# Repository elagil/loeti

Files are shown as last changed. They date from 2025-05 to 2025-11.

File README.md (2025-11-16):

# Löti

Soldering station hardware and firmware, powered by USB PD, delivering up to 100 W.

Supports irons with thermocouples as temperature probes, for example
- JBC C210
- JBC C245

## Resources

- [Hardware design](./hardware)
- [Firmware](./firmware)

## Updating firmware

On the device, either
- hold the `BOOT`-button on the PCB and insert the USB cable into the data/debug port, or
- go to the user menu (long-press encoder button), scroll down to `DFU mode`, and select.

Once in DFU mode, flash a binary from the release artifacts. For example with

```bash
dfu-util -a 0 -s 0x08000000:leave -D <firmware_file_name>.bin
```

## The finished product

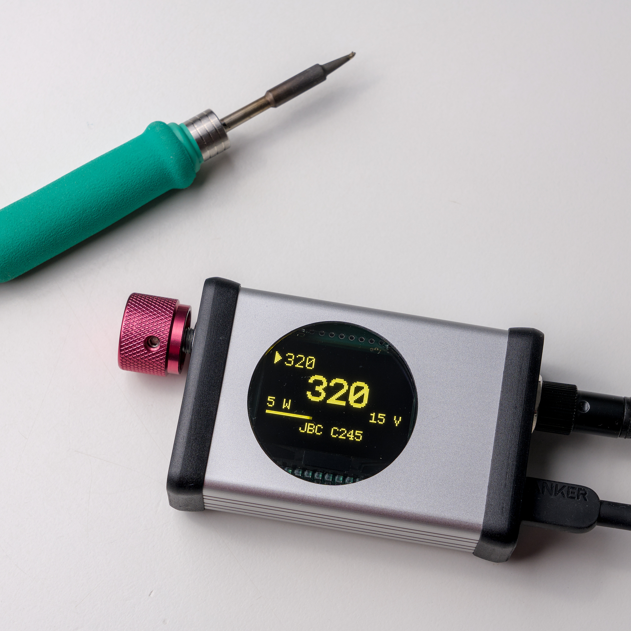
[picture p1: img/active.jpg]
Active

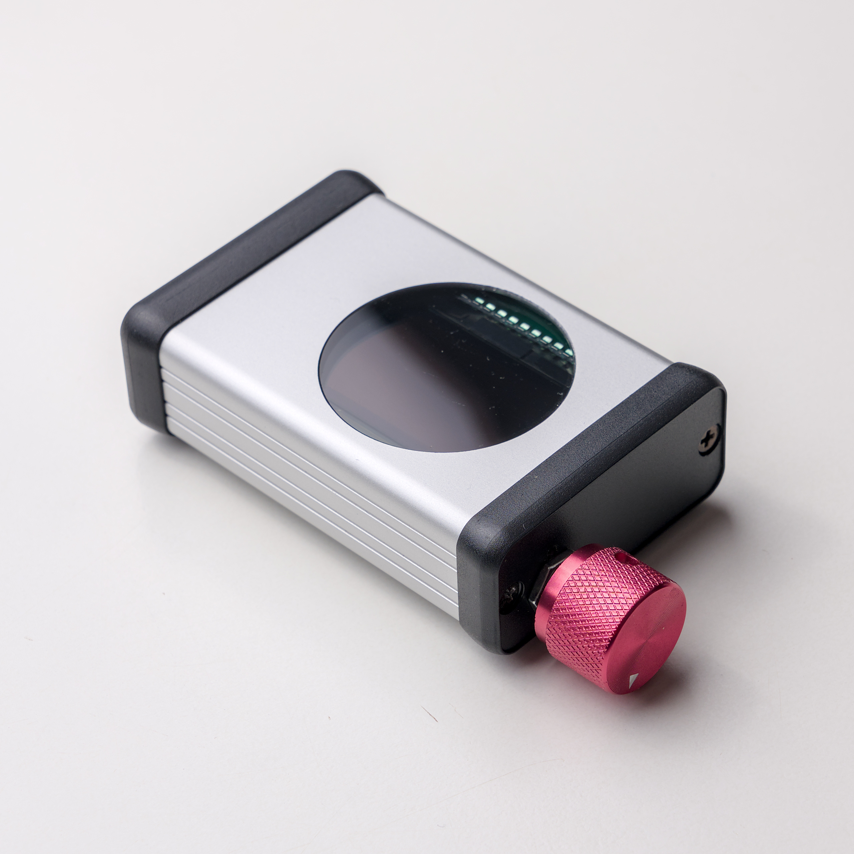
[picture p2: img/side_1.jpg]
Side 1

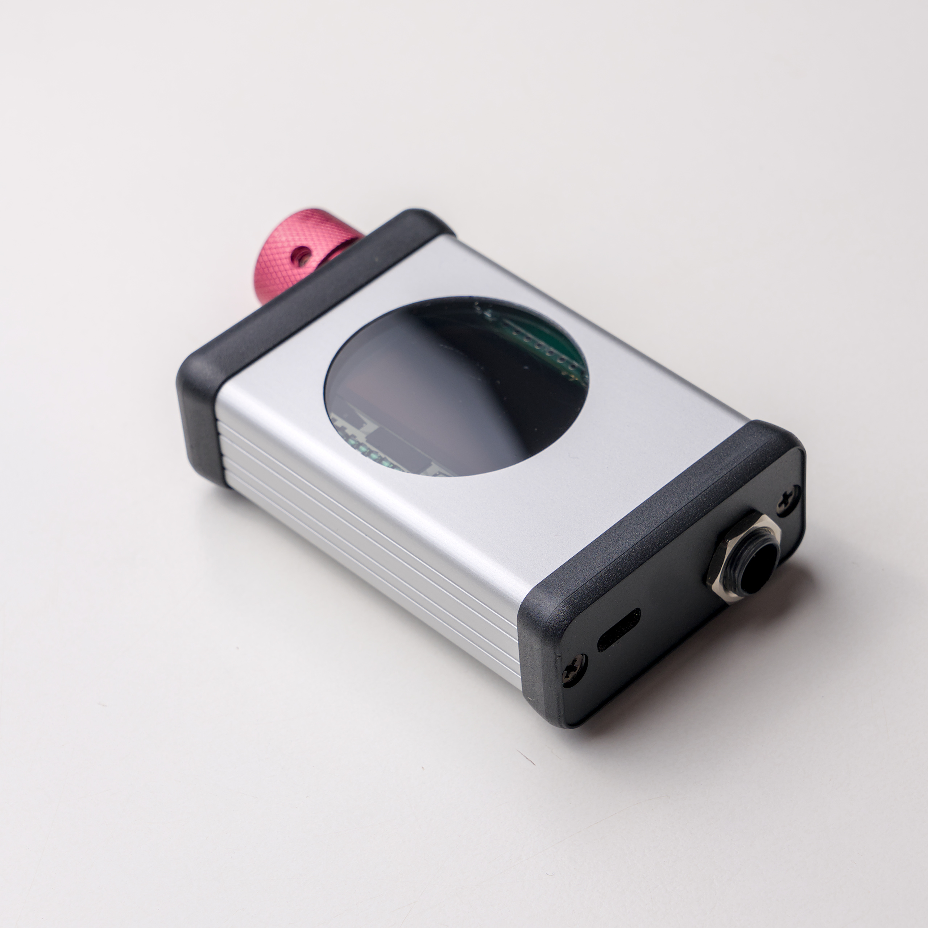
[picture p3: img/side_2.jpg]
Side 2

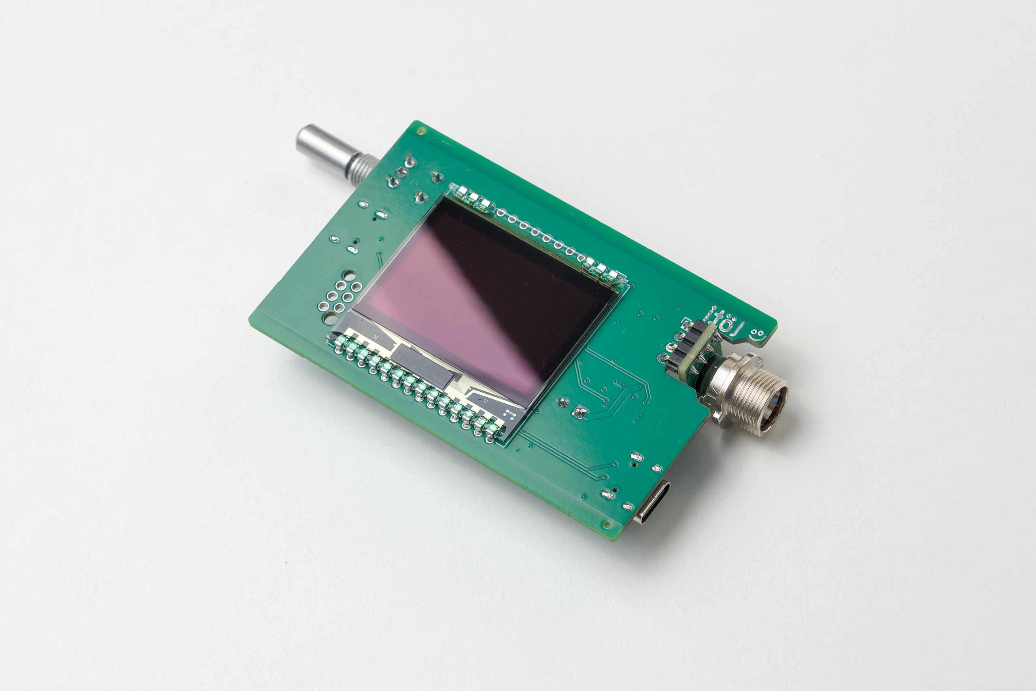
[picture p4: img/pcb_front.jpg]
Front

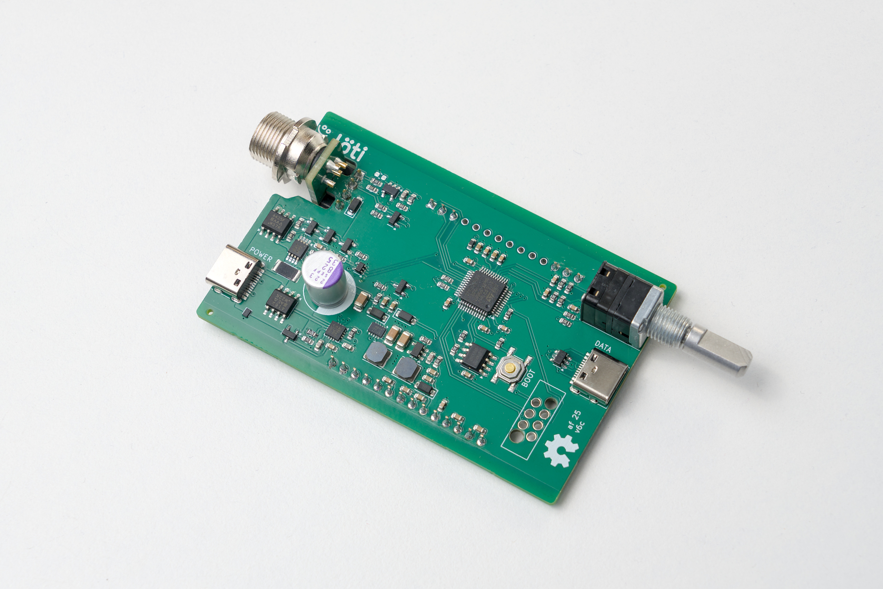
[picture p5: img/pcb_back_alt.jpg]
Back alt

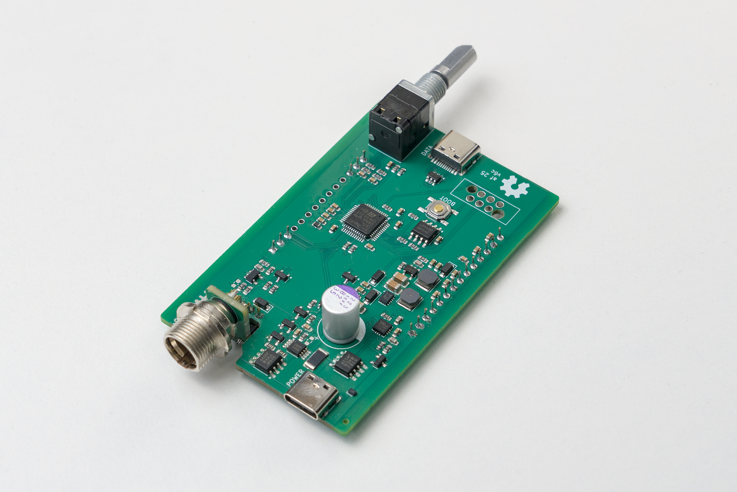
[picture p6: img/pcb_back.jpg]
Back


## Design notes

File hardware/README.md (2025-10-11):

# Hardware design

There are three PCBs that complete the build.

- The [main PCB](pcbs/main/),
- the [REAN TinyXLR adapter board](pcbs/adapter/), and
- a [holder for the acrylic display protection glass](pcbs/holder/).

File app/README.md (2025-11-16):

# Graphical user application

This is a GUI for observing the PID filter operation. It can be used to manually tune the PID filter in firmware.

## Usage

- Start this application with `RUST_LOG=INFO cargo run`.
- Connect a device that was built with the `comm` feature enabled.
- Display should start automatically.

## Permissions

On Linux, udev rules may have to be adjusted. Place [the rules file](./99-ergot.rules) in `/etc/udev/rules.d/` and run

```bash
sudo udevadm control --reload-rules && sudo udevadm trigger
```

for reloading the rules.

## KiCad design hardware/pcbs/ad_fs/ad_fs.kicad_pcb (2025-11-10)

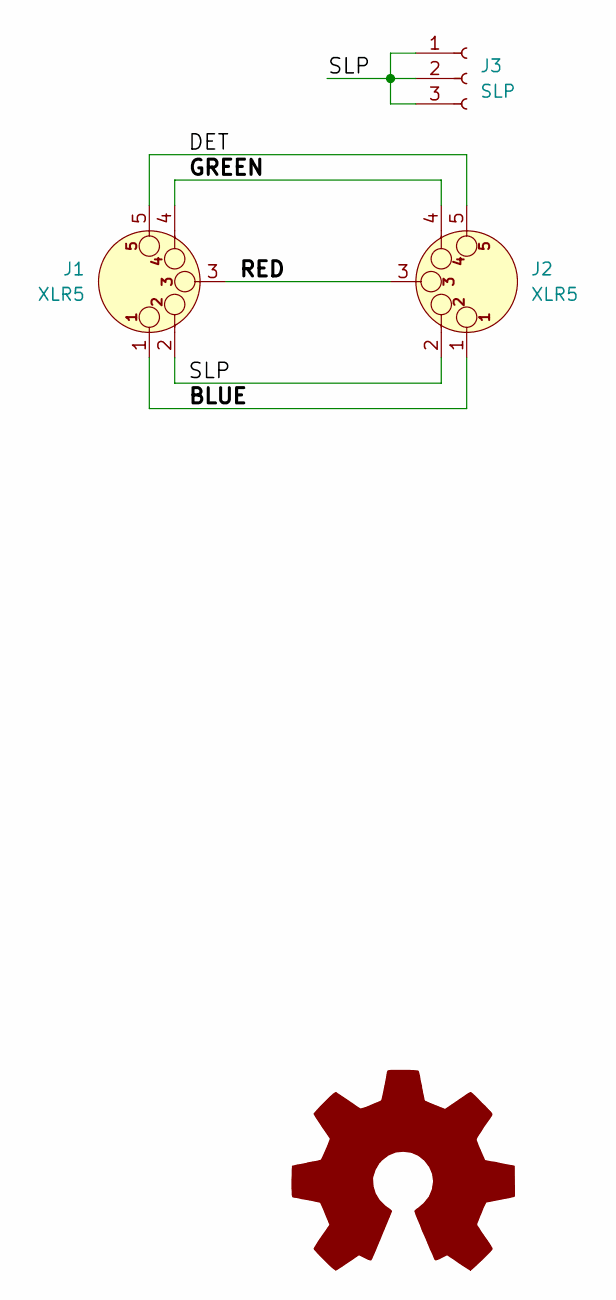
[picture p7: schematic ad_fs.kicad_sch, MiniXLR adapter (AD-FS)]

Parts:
J1, J2: XLR5; MiniXLR-5_Rean_RT5MPR
J3: SLP; PinSocket_1x03_P2.00mm_Vertical
oshw1: Logo_Open_Hardware_Large; OSHW-Symbol_6.7x6mm_SilkScreen

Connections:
/BLUE: J1.1, J2.1
/DET: J1.5, J2.5
/GREEN: J1.4 (P3), J2.4 (P3)
/RED: J1.3, J2.3
/SLP: J1.2, J2.2, J3.1, J3.2, J3.3

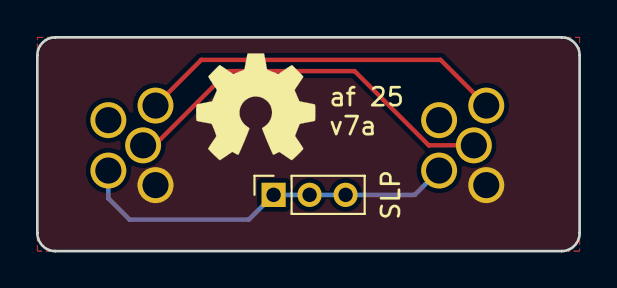
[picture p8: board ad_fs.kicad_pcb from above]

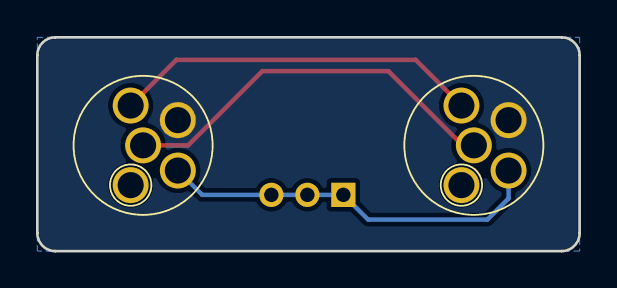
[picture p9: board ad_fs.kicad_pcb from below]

Board: 2 copper layers, 30.1 x 11.9 mm, 4 parts (2 on the bottom side), 5 nets.

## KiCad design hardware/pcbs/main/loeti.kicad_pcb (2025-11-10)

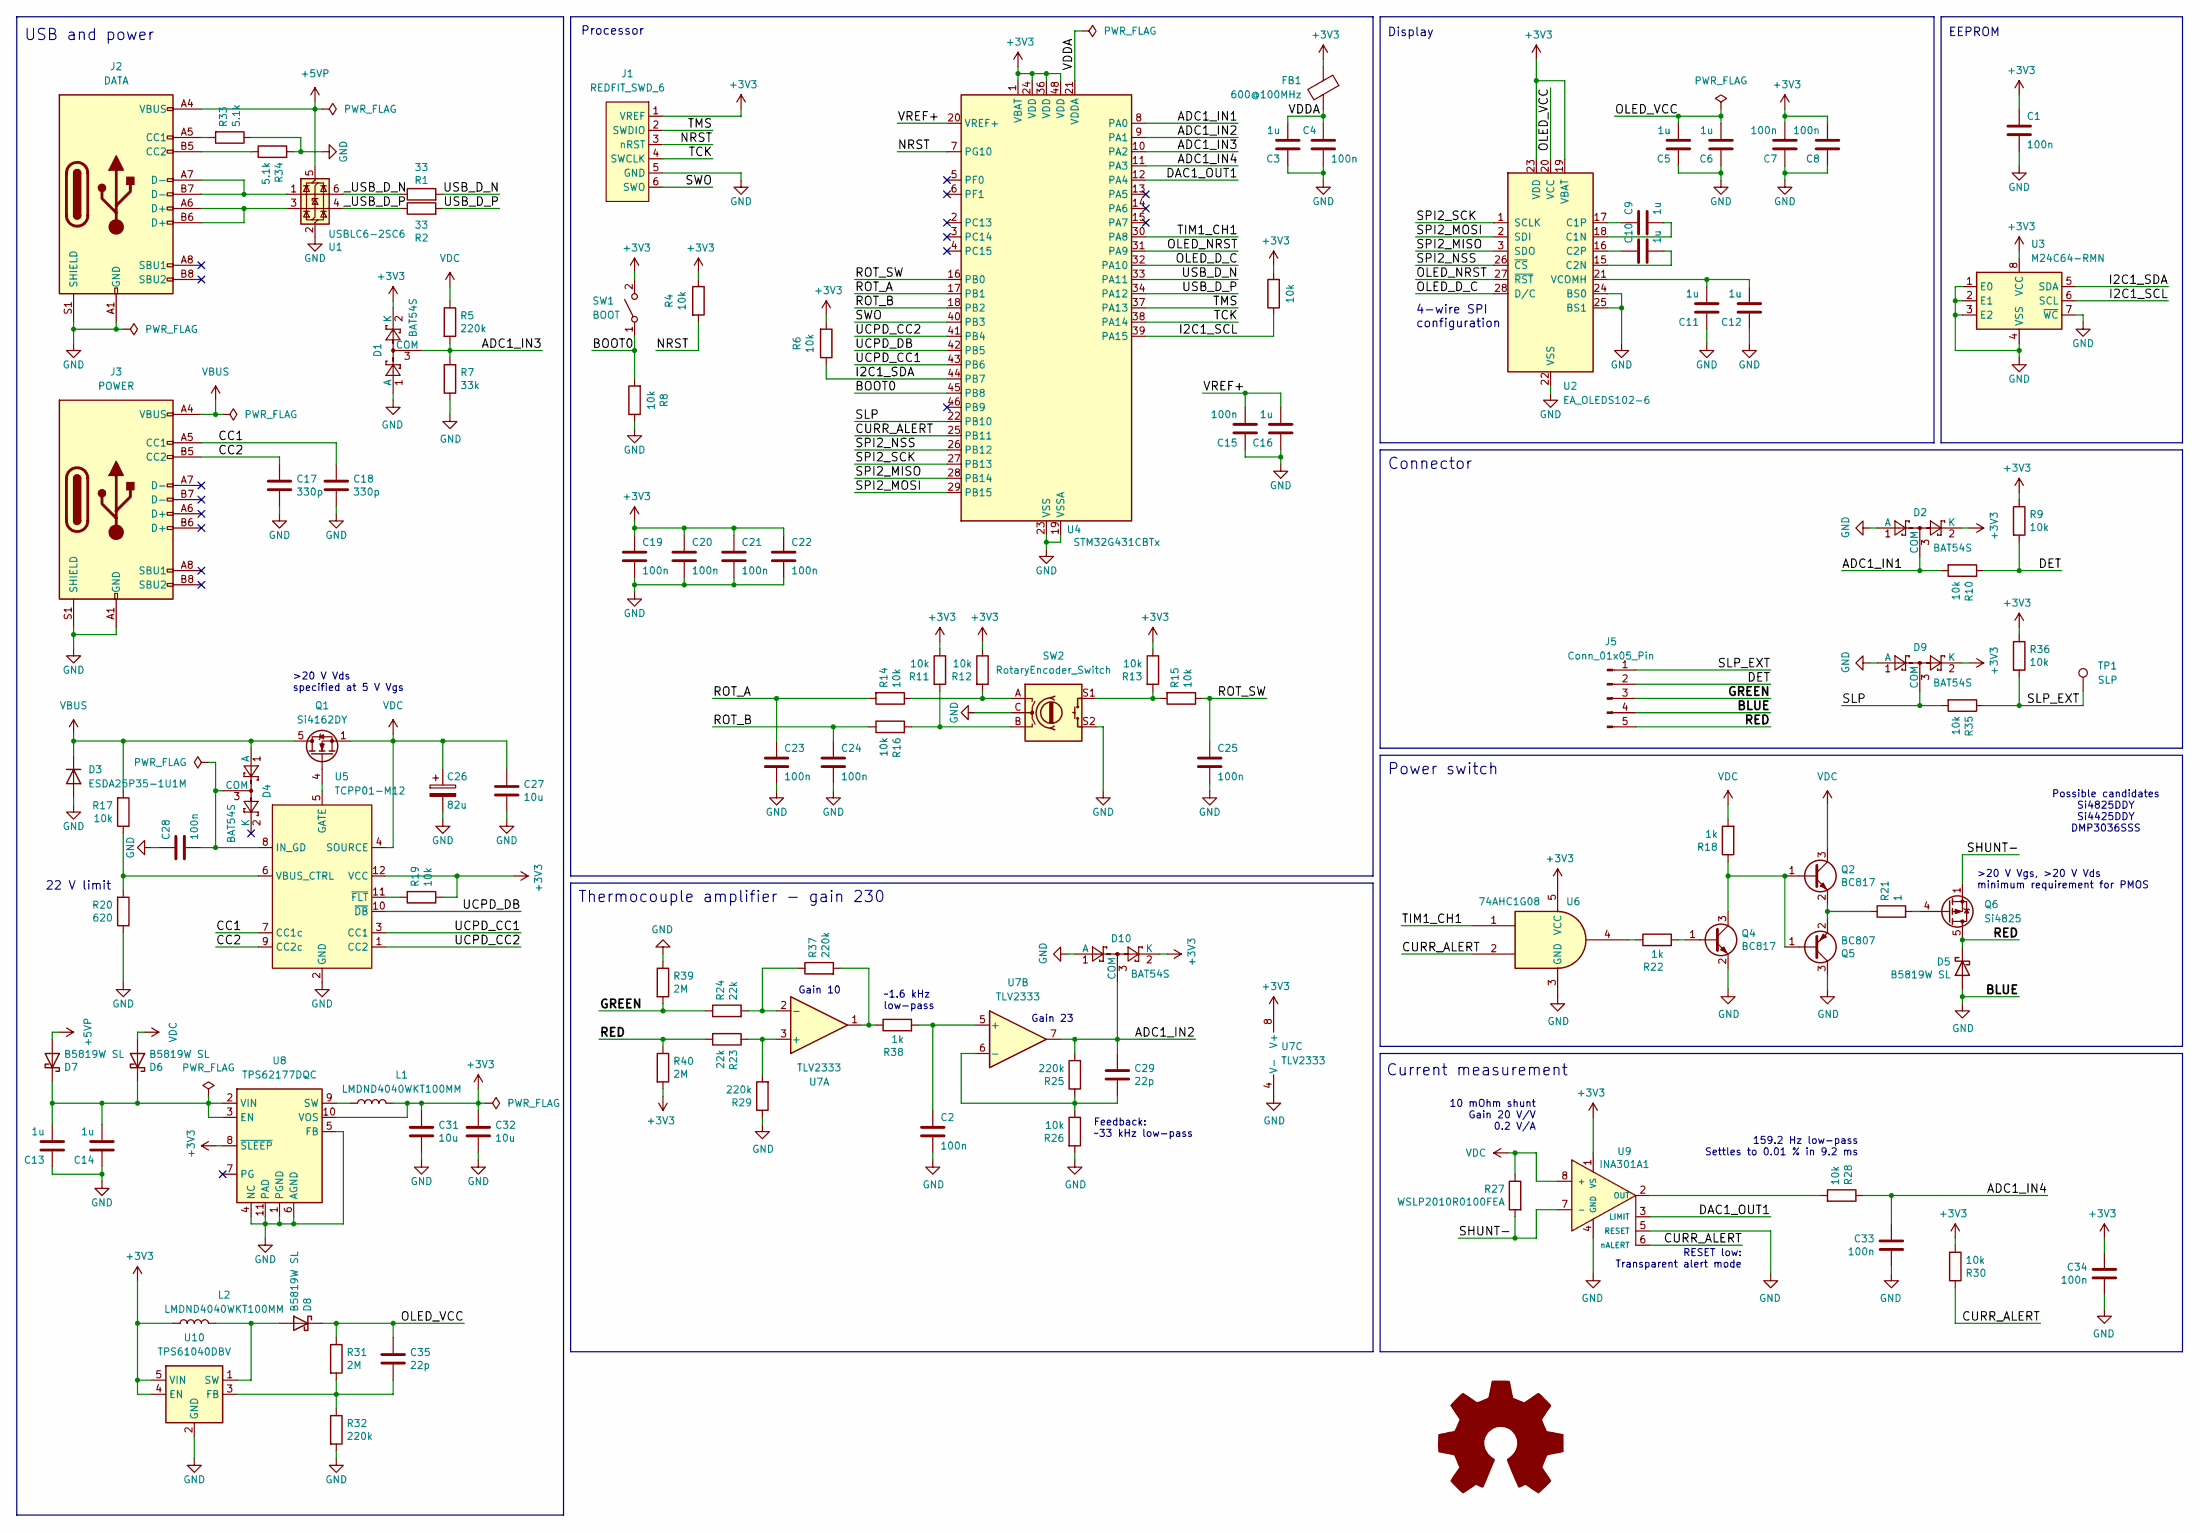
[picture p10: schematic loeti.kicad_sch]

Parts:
C1, C2, C4, C7, C8, C15, C19, C20, C21, C22, C23, C24, C25, C28, C33, C34: 100n; C_0603_1608Metric; MPN C14663
C3, C5, C6, C9, C10, C11, C12, C13, C14, C16: 1u; C_0603_1608Metric; MPN C15849
C17, C18: 330p; C_0603_1608Metric; MPN C1664
C26: 82u; CP_Radial_D8.0mm_P3.50mm
C27, C31, C32: 10u; C_1206_3216Metric; MPN C13585
C29, C35: 22p; C_0603_1608Metric; MPN C1653
D1, D2, D4, D9, D10: BAT54S; SOT-23; MPN C83935
D3: ESDA25P35-1U1M; ST_QFN-2L_1.6x1.0mm; MPN C1974707
D5, D6, D7, D8: B5819W SL; D_SOD-123; MPN C8598
FB1: 600@100MHz; L_0603_1608Metric; MPN C1002
J1: REDFIT_SWD_6; WR-WST REDFIT IDC 6 DBG
J2: DATA; USB_C_Receptacle_HRO_TYPE-C-31-M-12; MPN C165948
J3: POWER; USB_C_Receptacle_HRO_TYPE-C-31-M-12; MPN C165948
J5: Conn_01x05_Pin; PinHeader_1x05_P2.54mm_Horizontal
L1, L2: LMDND4040WKT100MM; L_Abracon_ASPI-0425
Q1: Si4162DY; SOIC-8_3.9x4.9mm_P1.27mm; MPN C727585
Q2, Q4: BC817; SOT-23; MPN C466643
Q5: BC807; SOT-23; MPN C466642
Q6: Si4825; SOIC-8_3.9x4.9mm_P1.27mm; MPN C3289788
R1, R2: 33; R_0603_1608Metric; MPN C23140
R3, R4, R6, R8, R9, R10, R11, R12, R13, R14, R15, R16, R17, R19, R26, R28, R30, R35, R36: 10k; R_0603_1608Metric; MPN C25804
R5, R25, R29, R32, R37: 220k; R_0603_1608Metric; MPN C22961
R7: 33k; R_0603_1608Metric; MPN C4216
R18, R22, R38: 1k; R_0603_1608Metric; MPN C21190
R20: 620; R_0603_1608Metric
R21: 1; R_0603_1608Metric; MPN C22936
R23, R24: 22k; R_0603_1608Metric; MPN C31850
R27: WSLP2010R0100FEA; R_2010_5025Metric; MPN C844087
R31, R39, R40: 2M; R_0603_1608Metric; MPN C22976
R33, R34: 5.1k; R_0603_1608Metric; MPN C23186
SW1: BOOT; SW_SPST_TL3342; MPN C318884
SW2: RotaryEncoder_Switch; RotaryEncoder_Bourns_Horizontal_PEC09-2xxxF-Sxxxx
TP1: SLP; TestPoint_Plated_Hole_D2.0mm
U1: USBLC6-2SC6; SOT-23-6; MPN C7519; JLCPCB Rotation Offset 180
U2: EA_OLEDS102-6
U3: M24C64-RMN; SOIC-8_3.9x4.9mm_P1.27mm; MPN C79988; JLCPCB Rotation Offset -90
U4: STM32G431CBTx; LQFP-48_7x7mm_P0.5mm; MPN C529355
U5: TCPP01-M12; QFN-12-1EP_3x3mm_P0.51mm_EP1.45x1.45mm; MPN C1121848
U6: 74AHC1G08; SOT-353_SC-70-5; MPN C459531
U7: TLV2333; SOIC-8_3.9x4.9mm_P1.27mm; MPN C176649
U8: TPS62177DQC; WSON-10-1EP_2x3mm_P0.5mm_EP0.84x2.4mm_ThermalVias; MPN C91241
U9: INA301A1; VSSOP-8_3x3mm_P0.65mm; MPN C471062
U10: TPS61040DBV; SOT-23-5
oshw1: Logo_Open_Hardware_Large; OSHW-Symbol_6.7x6mm_SilkScreen

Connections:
+3V3: C1.1, C7.2, C8.2, C19.1, C20.1, C21.1, C22.1, C31.1, C32.1, C34.1, D1.2 (K), D2.2 (K), D9.2 (K), D10.2 (K), FB1.1, J1.1 (VREF), L1.2, L2.1, R3.2, R4.1, R6.2, R9.1, R11.1, R12.1, R13.1, R19.1, R30.2, R36.1, R40.2, SW1.2 (B), U2.19 (VBAT), U2.23 (VDD), U3.8 (VCC), U4.1 (VBAT), U4.24 (VDD), U4.36 (VDD), U4.48 (VDD), U5.12 (VCC), U6.5 (VCC), U7.8 (V+), U8.8 (~SLEEP), U8.10 (VOS), U9.1 (VS), U10.4 (EN), U10.5 (VIN)
+5VP: D7.2 (A), J2.A4 (VBUS), J2.A9 (VBUS), J2.B4 (VBUS), J2.B9 (VBUS), U1.5 (VBUS)
/ADC1_IN1: D2.3 (COM), R10.2, U4.8 (PA0)
/ADC1_IN2: C29.1, D10.3 (COM), R25.2, U4.9 (PA1), U7.7
/ADC1_IN3: D1.3 (COM), R5.2, R7.2, U4.10 (PA2)
/ADC1_IN4: C33.1, R28.1, U4.11 (PA3)
/BOOT0: R8.2, SW1.1 (A), U4.45 (PB8)
/CC1: C18.1, J3.A5 (CC1), U5.7 (CC1c)
/CC2: C17.1, J3.B5 (CC2), U5.9 (CC2c)
/CURR_ALERT: R30.1, U4.25 (PB11), U6.2, U9.6 (nALERT)
/DAC1_OUT1: U4.12 (PA4), U9.3 (LIMIT)
/DET: J5.2, R9.2, R10.1
/GREEN: J5.3, R24.1, R39.2
/I2C1_SCL: R3.1, U3.6 (SCL), U4.39 (PA15)
/I2C1_SDA: R6.1, U3.5 (SDA), U4.44 (PB7)
/NRST: J1.3 (nRST), R4.2, U4.7 (PG10)
/OLED_D_C: U2.28 (D/C), U4.32 (PA10)
/OLED_NRST: U2.27 (~RST), U4.31 (PA9)
/OLED_VCC: C5.2, C6.2, C35.1, D8.1 (K), R31.1, U2.20 (VCC)
/RED: D5.1 (K), J5.5, Q6.5 (D), Q6.6 (D), Q6.7 (D), Q6.8 (D), R23.2, R40.1
/ROT_A: C23.1, R14.2, U4.17 (PB1)
/ROT_B: C24.1, R16.1, U4.18 (PB2)
/ROT_SW: C25.1, R15.1, U4.16 (PB0)
/SHUNT-: Q6.1 (S), Q6.2 (S), Q6.3 (S), R27.2, U9.7 (-)
/SLP: D9.3 (COM), R35.2, U4.22 (PB10)
/SLP_EXT: J5.1, R35.1, R36.2, TP1.1
/SPI2_MISO: U2.3 (SDO), U4.28 (PB14)
/SPI2_MOSI: U2.2 (SDI), U4.29 (PB15)
/SPI2_NSS: U2.26 (~CS), U4.26 (PB12)
/SPI2_SCK: U2.1 (SCLK), U4.27 (PB13)
/SWO: J1.6 (SWO), U4.40 (PB3)
/TCK: J1.4 (SWCLK), U4.38 (PA14)
/TIM1_CH1: U4.30 (PA8), U6.1
/TMS: J1.2 (SWDIO), U4.37 (PA13)
/UCPD_CC1: U4.43 (PB6), U5.3 (CC1)
/UCPD_CC2: U4.41 (PB4), U5.1 (CC2)
/UCPD_DB: U4.42 (PB5), U5.10 (~DB)
/USB_D_N: R1.2, U4.33 (PA11)
/USB_D_P: R2.2, U4.34 (PA12)
/VDDA: C3.2, C4.1, FB1.2, U4.21 (VDDA)
/VREF+: C15.2, C16.2, U4.20 (VREF+)
/_USB_D_N: R1.1, U1.6 (I/O1)
/_USB_D_P: R2.1, U1.4 (I/O2)
GND: C1.2, C2.2, C3.1, C4.2, C5.1, C6.1, C7.1, C8.1, C11.1, C12.1, C13.1, C14.1, C15.1, C16.1, C17.2, C18.2, C19.2, C20.2, C21.2, C22.2, C23.2, C24.2, C25.2, C26.2, C27.2, C28.1, C31.2, C32.2, C33.2, C34.2, D1.1 (A), D2.1 (A), D3.2 (A), D5.2 (A), D9.1 (A), D10.1 (A), J1.5 (GND), J2.A1 (GND), J2.A12 (GND), J2.B1 (GND), J2.B12 (GND), J2.S1 (SHIELD), J3.A1 (GND), J3.A12 (GND), J3.B1 (GND), J3.B12 (GND), J3.S1 (SHIELD), J5.4, Q4.2 (E), Q5.3 (C), R7.1, R8.1, R20.1, R26.2, R29.1, R32.2, R33.1, R34.2, R39.1, SW2.C, SW2.S2, U1.2 (GND), U2.22 (VSS), U2.24 (BS0), U2.25 (BS1), U3.1 (E0), U3.2 (E1), U3.3 (E2), U3.4 (VSS), U3.7 (~WC), U4.19 (VSSA), U4.23 (VSS), U4.35 (VSS), U4.47 (VSS), U5.2 (GND), U5.13 (GND), U6.3 (GND), U7.4 (V-), U8.1 (PGND), U8.4 (NC), U8.5 (FB), U8.6 (AGND), U8.11 (PAD), U9.4 (GND), U9.5 (RESET), U10.2 (GND)
unnamed: C28.2, D4.3 (COM), U5.8 (IN_GD)
unnamed: C13.2, C14.2, D6.1 (K), D7.1 (K), U8.2 (VIN), U8.3 (EN)
unnamed: D8.2 (A), L2.2, U10.1 (SW)
unnamed: J2.A5 (CC1), R33.2
unnamed: J2.B5 (CC2), R34.1
unnamed: J2.A6 (D+), J2.B6 (D+), U1.3 (I/O2)
unnamed: J2.A7 (D-), J2.B7 (D-), U1.1 (I/O1)
unnamed: Q1.4 (G), U5.5 (GATE)
unnamed: Q2.1 (B), Q4.3 (C), Q5.1 (B), R18.1
unnamed: Q2.2 (E), Q5.2 (E), R21.1
unnamed: Q4.1 (B), R22.2
unnamed: Q6.4 (G), R21.2
unnamed: R11.2, R16.2, SW2.B
unnamed: R12.2, R14.1, SW2.A
unnamed: R13.2, R15.2, SW2.S1
unnamed: R22.1, U6.4
unnamed: R37.2, R38.1, U7.1
unnamed: C9.2, U2.18 (C1N)
unnamed: C9.1, U2.17 (C1P)
unnamed: C10.2, U2.15 (C2N)
unnamed: C10.1, U2.16 (C2P)
unnamed: C11.2, C12.2, U2.21 (VCOMH)
unnamed: R17.1, R20.2, U5.6 (VBUS_CTRL)
unnamed: R19.2, U5.11 (~FLT)
unnamed: R23.1, R29.2, U7.3 (+)
unnamed: R24.2, R37.1, U7.2 (-)
unnamed: C2.1, R38.2, U7.5 (+)
unnamed: C29.2, R25.1, R26.1, U7.6 (-)
unnamed: L1.1, U8.9 (SW)
unnamed: R28.2, U9.2 (OUT)
unnamed: C35.2, R31.2, R32.1, U10.3 (FB)
VBUS: D3.1 (K), D4.1 (A), J3.A4 (VBUS), J3.A9 (VBUS), J3.B4 (VBUS), J3.B9 (VBUS), Q1.5 (D), Q1.6 (D), Q1.7 (D), Q1.8 (D), R17.2
VDC: C26.1, C27.1, D6.2 (A), Q1.1 (S), Q1.2 (S), Q1.3 (S), Q2.3 (C), R5.1, R18.2, R27.1, U5.4 (SOURCE), U9.8 (+)

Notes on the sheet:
~1.6 kHz low-pass
>20 V Vgs, >20 V Vds minimum requirement for PMOS
USB and power
22 V limit
>20 V Vds specified at 5 V Vgs
159.2 Hz low-pass Settles to 0.01 % in 9.2 ms
RESET low: Transparent alert mode
Connector
EEPROM
Possible candidates Si4825DDY Si4425DDY DMP3036SSS
Gain 23
Gain 10
Feedback: ~33 kHz low-pass
Thermocouple amplifier - gain 230
Power switch
4-wire SPI configuration
Display
Processor
10 mOhm shunt Gain 20 V/V 0.2 V/A
Current measurement

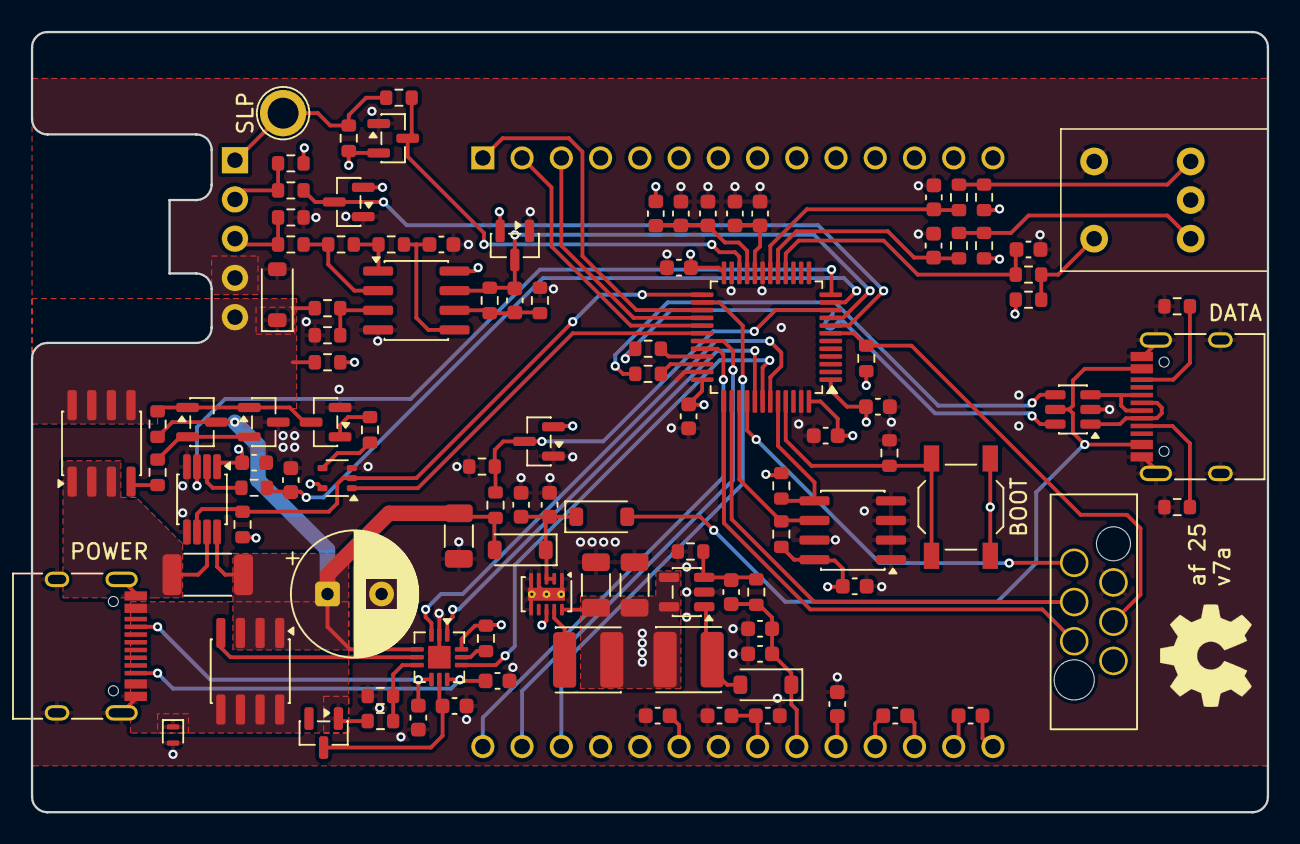
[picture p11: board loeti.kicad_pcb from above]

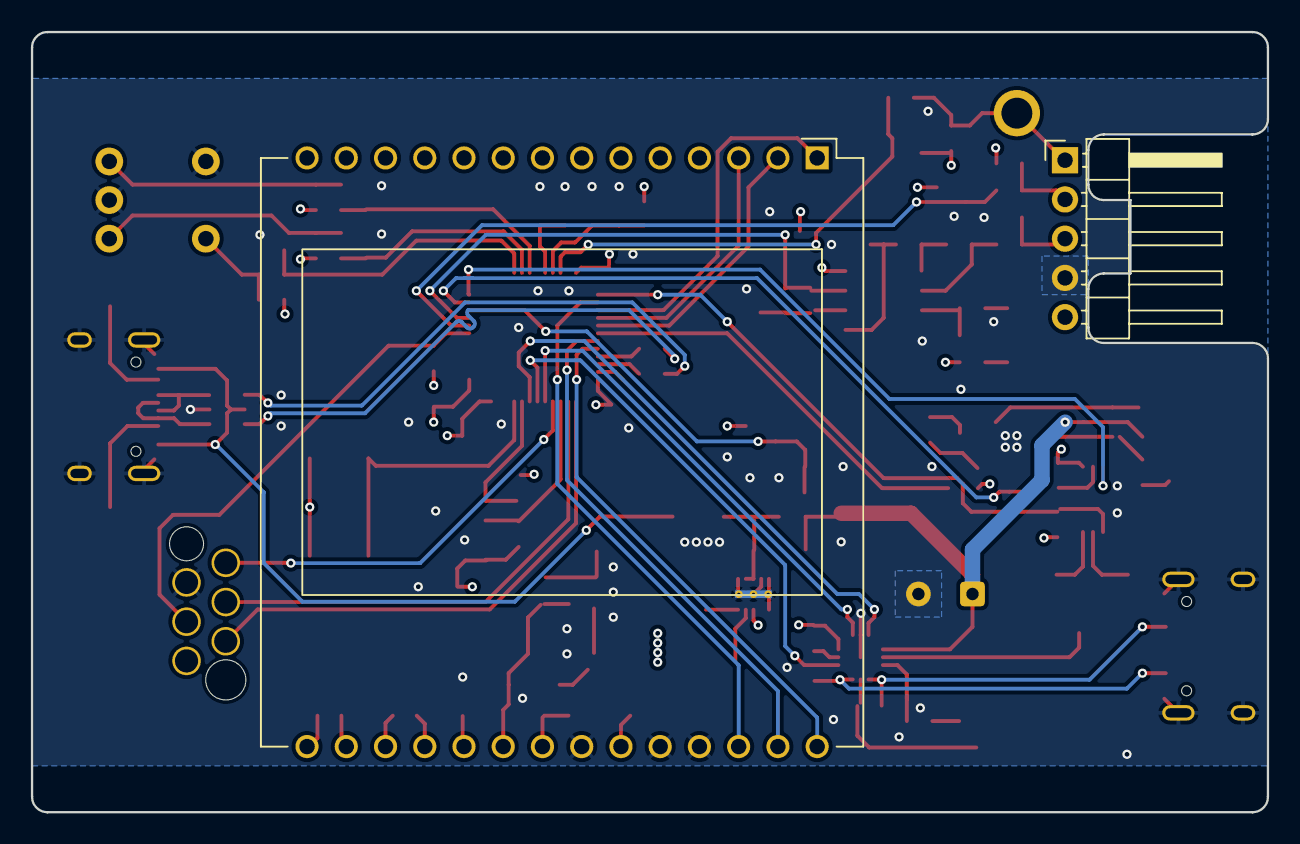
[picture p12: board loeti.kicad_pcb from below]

Board: 4 copper layers, 80.0 x 50.5 mm, 110 parts (2 on the bottom side), 77 nets.

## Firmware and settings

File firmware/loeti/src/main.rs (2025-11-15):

#![no_std]
#![no_main]

use defmt::{info, unwrap};
use embassy_executor::Spawner;
use embassy_stm32::exti::ExtiInput;
use embassy_stm32::gpio::{Input, Level, Output, OutputType, Pull, Speed};

use embassy_stm32::{Config, bind_interrupts, i2c, peripherals, usb};
use embassy_time::{Duration, WithTimeout};
use loeti::{split_resources, tool};
use {defmt_rtt as _, panic_probe as _};

bind_interrupts!(struct Irqs {
    USB_LP => usb::InterruptHandler<peripherals::USB>;
    I2C1_EV => i2c::EventInterruptHandler<peripherals::I2C1>;
    I2C1_ER => i2c::ErrorInterruptHandler<peripherals::I2C1>;
});

#[embassy_executor::main]
async fn main(spawner: Spawner) {
    info!("Hi");

    let mut config = Config::default();
    {
        use embassy_stm32::rcc::*;
        config.rcc.hsi = true;
        config.rcc.hse = None;
        config.rcc.pll = Some(Pll {
            source: PllSource::HSI,
            prediv: PllPreDiv::DIV4,
            mul: PllMul::MUL85,
            divp: Some(PllPDiv::DIV20), // 17 MHz ADC clock
            divq: None,
            divr: Some(PllRDiv::DIV2), // 170 MHz system clock
        });
        config.rcc.hsi48 = Some(Hsi48Config {
            sync_from_usb: true,
        });
        config.rcc.mux.adc12sel = mux::Adcsel::PLL1_P;
        config.rcc.mux.clk48sel = mux::Clk48sel::HSI48;
        config.rcc.sys = Sysclk::PLL1_R;
        config.enable_debug_during_sleep = true;
    }
    let p = embassy_stm32::init(config);
    let mut core_peri = cortex_m::Peripherals::take().unwrap();

    // Enable instruction cache.
    core_peri.SCB.enable_icache();

    // Launch USB PD power negotiation
    {
        use loeti::power;
        use loeti::power::{AssignedResources, UcpdResources};

        let resources = split_resources!(p);
        let ndb_pin = Output::new(p.PB5, Level::Low, Speed::Low);
        unwrap!(spawner.spawn(power::ucpd_task(resources.ucpd, ndb_pin)));
    }

    let negotiated_supply = loeti::NEGOTIATED_SUPPLY_SIG
        .wait()
        .with_timeout(Duration::from_secs(3))
        .await;

    // USB/RPC INIT
    #[cfg(feature = "comm")]
    {
        use loeti::comm::{self, MAX_PACKET_SIZE, OUT_QUEUE, STACK, STORAGE, kit};
        use static_cell::ConstStaticCell;

        let driver = usb::Driver::new(p.USB, Irqs, p.PA12, p.PA11);
        let config = comm::usb_config("123");
        let (device, tx_impl, ep_out) = STORAGE.init_ergot(driver, config);
        let rxvr: comm::RxWorker = kit::RxWorker::new(&STACK, ep_out);

        static RX_BUF: ConstStaticCell<[u8; MAX_PACKET_SIZE]> =
            ConstStaticCell::new([0u8; MAX_PACKET_SIZE]);

        spawner.must_spawn(comm::usb_task(device));
        spawner.must_spawn(comm::pingserver());
        spawner.must_spawn(comm::run_tx(tx_impl, OUT_QUEUE.framed_consumer()));
        spawner.must_spawn(comm::run_rx(rxvr, RX_BUF.take()));
    }

    // Launch EEPROM config storage
    {
        use loeti::eeprom;

        let i2c = i2c::I2c::new(
            p.I2C1,
            p.PA15,
            p.PB7,
            Irqs,
            p.DMA1_CH5,
            p.DMA1_CH3,
            Default::default(),
        );
        let mut eeprom = eeprom24x::Eeprom24x::new_24x64(i2c, eeprom24x::SlaveAddr::Default);

        const RESET: bool = false;
        if RESET {
            eeprom::store_defaults(&mut eeprom).await;
        }

        // Load data before any other tasks access persistent storage.
        eeprom::load_persistent(&mut eeprom).await;

        // Transfer persistent information to operational state.
        // FIXME: Make a method on the operational state itself?
        let power_on_heater_off =
            loeti::PERSISTENT_MUTEX.lock(|persistent| persistent.borrow().off_on_power);
        loeti::OPERATIONAL_STATE_MUTEX.lock(|operational| {
            operational.borrow_mut().tool_is_off = power_on_heater_off;
        });

        unwrap!(spawner.spawn(eeprom::eeprom_task(eeprom)));
    }

    // Launch display
    #[cfg(feature = "display")]
    {
        use embassy_stm32::spi;
        use loeti::ui::display;

        let _display_resources = {
            let mut spi_config = spi::Config::default();
            spi_config.frequency = embassy_stm32::time::Hertz(10_000_000);

            let spi = spi::Spi::new_txonly(p.SPI2, p.PB13, p.PB15, p.DMA2_CH1, spi_config);

            display::DisplayResources {
                spi,
                pin_dc: Output::new(p.PA10, Level::Low, Speed::High),
                pin_reset: Output::new(p.PA9, Level::Low, Speed::High),
                pin_cs: Output::new(p.PB12, Level::Low, Speed::High),
            }
        };
        unwrap!(spawner.spawn(display::display_task(_display_resources)));
    }

    // Launch UI with rotary encoder control
    {
        use loeti::ui;

        let rotary_encoder_resources = ui::encoder::RotaryEncoderResources {
            pin_sw: Input::new(p.PB0, Pull::None),
            pin_a: Input::new(p.PB1, Pull::None),
            pin_b: Input::new(p.PB2, Pull::None),
        };

        unwrap!(spawner.spawn(ui::encoder::rotary_encoder_task(rotary_encoder_resources)));
    }

    // Launch iron control
    if let Ok(negotiated_supply) = negotiated_supply {
        use embassy_stm32::adc::{Adc, AdcChannel};
        use embassy_stm32::dac::DacCh1;
        use embassy_stm32::pac::VREFBUF;
        use embassy_stm32::time::khz;
        use embassy_stm32::timer::simple_pwm::PwmPin;
        use embassy_stm32::timer::simple_pwm::SimplePwm;
        use loeti::tool::{AdcResources, ToolResources};

        VREFBUF.csr().write(|w| {
            w.set_envr(true);
            w.set_hiz(embassy_stm32::pac::vrefbuf::vals::Hiz::CONNECTED);
            w.set_vrs(embassy_stm32::pac::vrefbuf::vals::Vrs::VREF2);
        });

        let mut adc = Adc::new(p.ADC1);
        adc.set_oversampling_ratio(5); // 64x
        adc.set_oversampling_shift(2); // Scale back to 16 bit
        adc.enable_regular_oversampling_mode(
            embassy_stm32::adc::vals::Rovsm::RESUMED,
            embassy_stm32::adc::vals::Trovs::AUTOMATIC,
            true,
        );

        let tool_resources = ToolResources {
            adc_resources: AdcResources {
                adc,
                pin_temperature: p.PA0.degrade_adc(),
                pin_detect: p.PA1.degrade_adc(),
                pin_voltage: p.PA2.degrade_adc(),
                pin_current: p.PA3.degrade_adc(),
                adc_dma: p.DMA1_CH6,
            },
            dac_current_limit: DacCh1::new_blocking(p.DAC1, p.PA4),
            exti_current_alert: ExtiInput::new(p.PB11, p.EXTI11, Pull::None),
            pwm_heater: SimplePwm::new(
                p.TIM1,
                Some(PwmPin::new(p.PA8, OutputType::PushPull)),
                None,
                None,
                None,
                khz(34),
                Default::default(),
            ),
            pin_sleep: Input::new(p.PB10, Pull::Up),
        };

        unwrap!(spawner.spawn(tool::tool_task(tool_resources, negotiated_supply)));
    }
}

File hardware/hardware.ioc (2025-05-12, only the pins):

Mcu.UserName=STM32G431C6Tx
PA0.Signal=ADC2_IN1
PA1.Signal=ADC2_IN2
PA10.Signal=GPIO_Output
PA11.Signal=USB_DM
PA12.Signal=USB_DP
PA13.Signal=SYS_JTMS-SWDIO
PA14.Signal=SYS_JTCK-SWCLK
PA15.Signal=I2C1_SCL
PA2.Signal=ADC1_IN3
PA3.Signal=ADC1_IN4
PA4.Signal=COMP_DAC11_group
PA5.Signal=GPIO_Input
PA8.Signal=GPIO_Output
PA9.Signal=GPIO_Output
PB0.Signal=GPIO_Input
PB1.Signal=GPIO_Input
PB11.Signal=S_TIM2_CH4
PB12.Signal=SPI2_NSS
PB13.Signal=SPI2_SCK
PB14.Signal=SPI2_MISO
PB15.Signal=SPI2_MOSI
PB2.Signal=GPIO_Input
PB4.Signal=UCPD1_CC2
PB6.Signal=UCPD1_CC1
PB7.Signal=I2C1_SDA
PC15-OSC32_OUT.Signal=GPXTI15
PF0-OSC_IN.Signal=RCC_OSC_IN

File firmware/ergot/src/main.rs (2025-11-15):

#![no_std]
#![no_main]

use ergot::{
    exports::bbq2::{prod_cons::framed::FramedConsumer, traits::coordination::cs::CsCoord},
    fmt,
    interface_manager::InterfaceState,
    interface_manager::Profile,
    toolkits::embassy_usb_v0_5 as kit,
};

use defmt::{info, unwrap};
use embassy_executor::Spawner;
use embassy_stm32::exti::ExtiInput;
use embassy_stm32::gpio::{Input, Level, Output, OutputType, Pull, Speed};
use embassy_stm32::peripherals::USB;
use embassy_stm32::time::Hertz;
use embassy_stm32::{Config, bind_interrupts, i2c, peripherals, usb};
use embassy_time::{Duration, Ticker, WithTimeout};
use loeti_protocol::{Measurement, MeasurementTopic};
use mutex::raw_impls::cs::CriticalSectionRawMutex;
use {defmt_rtt as _, panic_probe as _};

bind_interrupts!(struct Irqs {
    USB_LP => usb::InterruptHandler<peripherals::USB>;
    I2C1_EV => i2c::EventInterruptHandler<peripherals::I2C1>;
    I2C1_ER => i2c::ErrorInterruptHandler<peripherals::I2C1>;
});

const OUT_QUEUE_SIZE: usize = 1024;
const MAX_PACKET_SIZE: usize = 128;

/// Our USB driver
pub type AppDriver = usb::Driver<'static, USB>;
/// The type of our netstack
type Stack = kit::Stack<&'static Queue, CriticalSectionRawMutex>;
/// The type of our outgoing queue
type Queue = kit::Queue<OUT_QUEUE_SIZE, CsCoord>;

/// Statically store our outgoing packet buffer
static OUT_QUEUE: Queue = kit::Queue::new();
/// Statically store our USB app buffers
static STORAGE: kit::WireStorage<256, 256, 64, 256> = kit::WireStorage::new();
/// Statically store our netstack
static STACK: Stack = kit::new_target_stack(OUT_QUEUE.framed_producer(), MAX_PACKET_SIZE as u16);

fn usb_config(serial: &'static str) -> embassy_usb::Config<'static> {
    let mut config = embassy_usb::Config::new(0x16c0, 0x27DD);
    config.manufacturer = Some("OneVariable");
    config.product = Some("ergot-pico");
    config.serial_number = Some(serial);

    // Required for windows compatibility.
    // https://developer.nordicsemi.com/nRF_Connect_SDK/doc/1.9.1/kconfig/CONFIG_CDC_ACM_IAD.html#help
    config.device_class = 0xEF;
    config.device_sub_class = 0x02;
    config.device_protocol = 0x01;
    config.composite_with_iads = true;

    config
}

/// This handles the low level USB management
#[embassy_executor::task]
pub async fn usb_task(mut usb: embassy_usb::UsbDevice<'static, AppDriver>) {
    usb.run().await;
}

#[embassy_executor::task]
async fn run_tx(
    mut ep_in: <AppDriver as embassy_usb::driver::Driver<'static>>::EndpointIn,
    rx: FramedConsumer<&'static Queue>,
) {
    kit::tx_worker::<AppDriver, OUT_QUEUE_SIZE, CsCoord>(
        &mut ep_in,
        rx,
        kit::DEFAULT_TIMEOUT_MS_PER_FRAME,
        kit::USB_FS_MAX_PACKET_SIZE,
    )
    .await;
}

#[embassy_executor::task]
async fn pingserver() {
    STACK.services().ping_handler::<4>().await;
}

#[embassy_executor::main]
async fn main(spawner: Spawner) {
    info!("Hi");

    let mut config = Config::default();
    {
        use embassy_stm32::rcc::*;
        config.rcc.hsi = true;
        config.rcc.hse = None;
        config.rcc.pll = Some(Pll {
            source: PllSource::HSI,
            prediv: PllPreDiv::DIV4,
            mul: PllMul::MUL85,
            divp: Some(PllPDiv::DIV20), // 17 MHz ADC clock
            divq: None,
            divr: Some(PllRDiv::DIV2), // 170 MHz system clock
        });
        config.rcc.hsi48 = Some(Hsi48Config {
            sync_from_usb: true,
        });
        config.rcc.mux.adc12sel = mux::Adcsel::PLL1_P;
        config.rcc.mux.clk48sel = mux::Clk48sel::HSI48;
        config.rcc.sys = Sysclk::PLL1_R;
        config.enable_debug_during_sleep = true;
    }
    let p = embassy_stm32::init(config);
    let mut core_peri = cortex_m::Peripherals::take().unwrap();

    // Enable instruction cache.
    core_peri.SCB.enable_icache();

    // USB/RPC INIT
    {
        let driver = usb::Driver::new(p.USB, Irqs, p.PA12, p.PA11);
        let config = usb_config("123");
        let (device, tx_impl, _ep_out) = STORAGE.init_ergot(driver, config);

        spawner.must_spawn(usb_task(device));
        spawner.must_spawn(pingserver());
        spawner.must_spawn(run_tx(tx_impl, OUT_QUEUE.framed_consumer()));

        // Wait for connection
        let mut ticker = Ticker::every(Duration::from_millis(500));
        loop {
            ticker.next().await;

            let has_addr = STACK.manage_profile(|p| {
                let Some(state) = p.interface_state(()) else {
                    return false;
                };

                info!("{:?}", state);

                let InterfaceState::Active { net_id, .. } = state else {
                    return false;
                };
                net_id != 0
            });

            if has_addr {
                STACK.info_fmt(fmt!("Connected"));
                break;
            }
        }

        loop {
            ticker.next().await;
            // Publish data
            let measurement = Measurement {
                seq: 10,
                p: 0.1,
                i: 0.2,
                d: 0.3,
                temperature_deg_c: 123.0,
            };
            _ = STACK
                .topics()
                .broadcast::<MeasurementTopic>(&measurement, None);
        }
    }
}

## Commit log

2020-03-31 updates to bom initial software structure
    [loeti.csv, loeti.kicad_pcb, loeti.sch]
2020-04-02 adjustments to lcd driver
2020-04-02 prepared board files
2020-04-03 finalized lcd driver
2020-04-05 changes to spi handling changes to adc control added heater
2020-04-13 usb pd working new layout
    [loeti.kicad_pcb, loeti.sch]
2020-05-03 fully working revision
    [loeti-B_Cu.gbr, loeti-B_Mask.gbr, loeti-B_Paste.gbr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]
2020-05-04 improved UI
    [loeti.sch]
2020-05-04 PCB v3 initial
    [loeti.kicad_pcb]
2020-05-08 cold junction compensation v3 hardware
    [loeti-B_Cu.gbr, loeti-B_Mask.gbr, loeti-B_Paste.gbr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]
2020-05-20 updates to schematic
    [loeti.sch]
2020-05-27 Switched to chibios 20.3.1
    [loeti.kicad_pcb, loeti.sch]
2020-05-27 Ported to ChibiOS 20
    [loeti.kicad_pcb]
2020-06-02 v4, stusb final
    [loeti.kicad_pcb, loeti.sch]
2020-06-04 v4 production version
    [loeti-B_Mask.gbr, loeti-B_Paste.gbr, loeti-B_SilkS.gbr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]
2020-06-20 missing footprint
    [loeti.csv, loeti.kicad_pcb]
2020-06-21 port to v4
    [loeti.csv]
2020-10-08 PORT STM32F030->STM32F042
2021-04-16 preliminary layout
    [loeti-B_Cu.gbr, loeti-B_Mask.gbr, loeti-B_Paste.gbr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]
2021-04-20 production version, v5
    [loeti-B_Cu.gbr, loeti-B_Mask.gbr, loeti-B_Paste.gbr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]
2021-04-20 production version, v5, addendum
    [loeti.kicad_pcb]
2021-05-04 final hardware
    [loeti-B_Cu.gbl, loeti-B_Mask.gbs, loeti-B_Paste.gbp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]
2021-05-07 software fixes for correct adc operation (wip)
    [loeti.kicad_pcb]
2021-05-07 firmware for v5
    [loeti.sch]
2021-05-08 software features fully working
    [loeti.sch]
2021-05-08 two-temperature mode
    [loeti.kicad_pcb, loeti.sch]
2021-05-08 improved display v5b complete
    [loeti.kicad_pcb, loeti.sch]
2021-05-13 initiali loeti tiny
    [loeti.kicad_pcb, loeti.sch]
2024-12-03 feat: loeti v5
    [loeti.kicad_pcb, loeti.kicad_sch]
2024-12-03 feat: initial software
    [loeti-B_Cu.gbl, loeti-B_Mask.gbs, loeti-B_Paste.gbp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]
2024-12-03 feat: initial display implementation
    [loeti.kicad_pcb, loeti.kicad_sch]
2024-12-03 feat: enable dac
    [loeti.kicad_pcb, loeti.kicad_sch]
2024-12-03 fix: adc assignments
    [loeti.kicad_pcb, loeti.kicad_sch]
2024-12-04 feat: add further pins
    [loeti.kicad_pcb, loeti.kicad_sch]
2024-12-12 feat: rev a production version
    [loeti.kicad_pcb, loeti.kicad_sch]
2025-01-10 feat: full features
    [loeti.kicad_pcb, loeti.kicad_sch]
2025-01-26 chore: clean up submodules
    [loeti.kicad_pcb, loeti.kicad_sch]
2025-03-30 fix: working revision
    [loeti.kicad_pcb, loeti.kicad_sch]
2025-05-12 chore: update PCB design
    [loeti.kicad_pcb, loeti.kicad_sch]
2025-06-13 chore: generate production outputs
    [loeti.kicad_pcb, loeti.kicad_sch]
2025-07-01 fix: hardware issues
    [loeti.kicad_pcb, loeti.kicad_sch]
2025-07-01 fix: pcb for minor mistakes
    [loeti.kicad_pcb, loeti.kicad_sch]
2025-07-04 fix: sleep behaviour * cleanup code structure * display improvements
    [display.rs, mod.rs, ui.rs]
2025-07-28 feat: initial menu (dummy)
    [loeti.kicad_pcb]
2025-07-28 fix: usable menu
    [loeti.kicad_pcb]
2025-08-03 feat: adjustable current margin
2025-08-06 fix: display adjustments - PCB screen location
    [loeti.kicad_pcb]
2025-08-20 feat: holder
    [holder.kicad_pcb, loeti.kicad_pcb, loeti.kicad_sch]
2025-08-20 feat: hardware modules for new XLR connector
    [adapter.kicad_pcb, adapter.kicad_sch, holder.kicad_pcb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]
2025-08-20 chore: structure PCBs
    [adapter.kicad_pcb, adapter.kicad_sch, holder.kicad_pcb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]
2025-08-20 chore: finalize v6c production run
    [adapter.kicad_pcb, holder.kicad_pcb, loeti.kicad_pcb]
2025-09-03 fix: v6d hardware, CC resistors on data port
    [loeti.kicad_pcb, loeti.kicad_sch]
2025-09-03 chore: update embassy, selectable sleep on error/power
    [display.rs, main.rs, mod.rs]
2025-10-11 feat: sleep support on PCB
    [adapter.kicad_pcb, adapter.kicad_sch, loeti.kicad_pcb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]
2025-10-18 fix: slower current loop
    [mod.rs]
2025-10-18 fix: remove unused module
    [mod.rs]
2025-10-18 fix: input direction change on display rotation - add quadratic c245 comp. term
    [encoder.rs]
2025-10-18 fix: show temp above 60 dg
    [display.rs]
2025-10-18 feat: update to 5-pin XLR for sleep
    [adapter.kicad_pcb, adapter.kicad_sch, loeti.kicad_pcb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]
2025-10-18 feat: use ADC oversampling
2025-10-18 fix: sleep pin
2025-10-19 fix: improve temperature measurement logic
    [display.rs, mod.rs]
2025-10-26 feat: improve code structure, EEPROM with checksum
    [ad_fs.kicad_pcb, ad_fs.kicad_sch, loeti.kicad_sch]
2025-10-26 fix: pmos type
    [loeti.kicad_sch]
2025-10-26 fix: temperature control and logic
    [display.rs, eeprom.rs, mod.rs]
2025-10-26 fix: downward setpoint undershoot
    [mod.rs]
2025-10-26 fix: reduce default logging
    [encoder.rs, main.rs, mod.rs]
2025-10-26 fix: docstrings and naming
    [display.rs, mod.rs]
2025-10-26 fix: docstrings and names
    [display.rs]
2025-10-26 chore: refactor draw logic - fix heater temp. creep
    [display.rs, encoder.rs, mod.rs]
2025-10-26 fix: current downward setpoint undershoot
    [mod.rs]
2025-10-26 fix: stand temp in persistent memory
    [display.rs, mod.rs]
2025-10-26 fix: remove sleep by default
    [mod.rs]
2025-11-10 feat: v7a initial hardware design
    [loeti.kicad_pcb, loeti.kicad_sch]
2025-11-10 feat: support multiple board variants
    [loeti.kicad_pcb, loeti.kicad_sch]
2025-11-10 feat: hw v7a
    [ad_fs.kicad_pcb, ad_fs.kicad_sch, adapter.kicad_pcb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]
2025-11-15 feat: app for PID tuning
2025-11-16 chore: modularize boards
2025-11-16 fix: ADC and PID tuning
    [app.rs, mod.rs]
2025-12-01 refactor: heater channel access
2026-02-07 feat: show negotiated power when idle
